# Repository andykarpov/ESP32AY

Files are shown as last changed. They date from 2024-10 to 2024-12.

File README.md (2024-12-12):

# ESP32AY multiformat Turbo Sound player 

## (archived outdated fork, please use the original repo for fresh sources including the PCB)

ESP32 based AY Turbo Sound multiformat player

## Fast flash firmware avaliable on [Alex Spawn OTA web page](https://ota.alexspawn.ru)

## Features
### Supported formats:
- .ayl - [Ay_Emul](https://bulba.untergrund.net/emulator_e.htm) by Sergey Bulba own playlist format
- .pt1 - Pro Tracker v1 file format
- .pt2 - Pro Tracker v2 file format
- .pt3 - Pro Tracker v3 (include Turbo Sound on two AY chips) file format
- .stc - Sound Tracker file format
- .stp - Sound Tracker Pro file format
- .asc - Sound Master file format 
- .psc - Pro Sound Creator file format
- .sqt - SQ Tracker file format
- .ay  - AY file format
- .psg - Programmable Sound Generator file format
- .rsf - Registers Stream Flow file format
- .yrg - [Custom AVR-AY format](https://www.avray.ru/ru/avr-ay-player/)
- UART mode (available in player settings menu as Player source)

### Controls
- Encoder Hold - change mode player/file browser
- Encoder Click - in player mode - play/pause; in file browser mode select track/playlist/directory; select - in config mode
- Encoder Double click - in player mode - open settings
- Encoder Push and turn right - fast forward (for ay format change next subsong)
- Encoder Push and turn left - slow down (for ay format change previous subsong)
- Left button click/hold - volume - (in player mode); cancel - in config mode
- Right button click/hold - volume + (in player mode)
- Left button double click - change AY clock (in player mode)
- Right button double click - change play mode: all/shuffle/once (in player mode)

### Playing modes:
- Playing all tracks (in folder/playlist)
- Playing random track (in folder/playlist)
- Playing once track (loop)

### Supports fully realtime file browser

### Supports realtime AY layers change:
- ABC
- ACB
- BAC
- BCA
- CAB
- CBA

### Supports realtime AY clock change:
- ZX SPECTRUM - 1773400 Hz
- PENTAGON - 1750000 Hz
- MSX - 1789772 Hz
- CPC - 1000000 Hz
- ATARI ST - 2000000 Hz

### Built-in battery

### Built-in charger and indication on LED and TFT

### Built-in headphones stereo amplifier controlled by I2C bus

## Demo video with digital sound record:

Watch the video (https://youtu.be/-dr-m1xszBs)

### UPD 22.10.2024
- Add new feature: "UART mode" with AVR-AY player through UART.

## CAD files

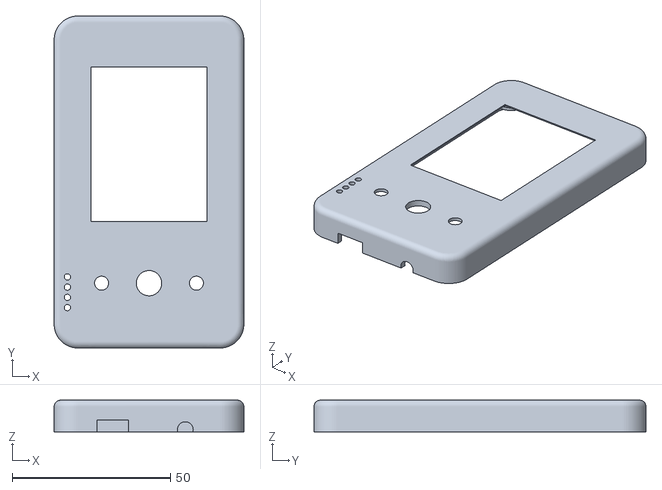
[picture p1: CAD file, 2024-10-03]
Case/ESP32AYTopTypeC.stl
60.0 x 105.0 x 10.00

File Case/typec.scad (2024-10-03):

$fn = 100;

pcb = "ESP32AY.stl";

if (false)
{
  translate([0, 0, 0.6]) 
  {
    rotate([0,0,0]) color("lightgray") import(pcb);
  }
}


difference() {
    
    #import("ESP32AYTop.stl");

    translate([36, -115, -1.45])
        rotate([0, 90, 90])
            cube([4, 10, 30], true);
}

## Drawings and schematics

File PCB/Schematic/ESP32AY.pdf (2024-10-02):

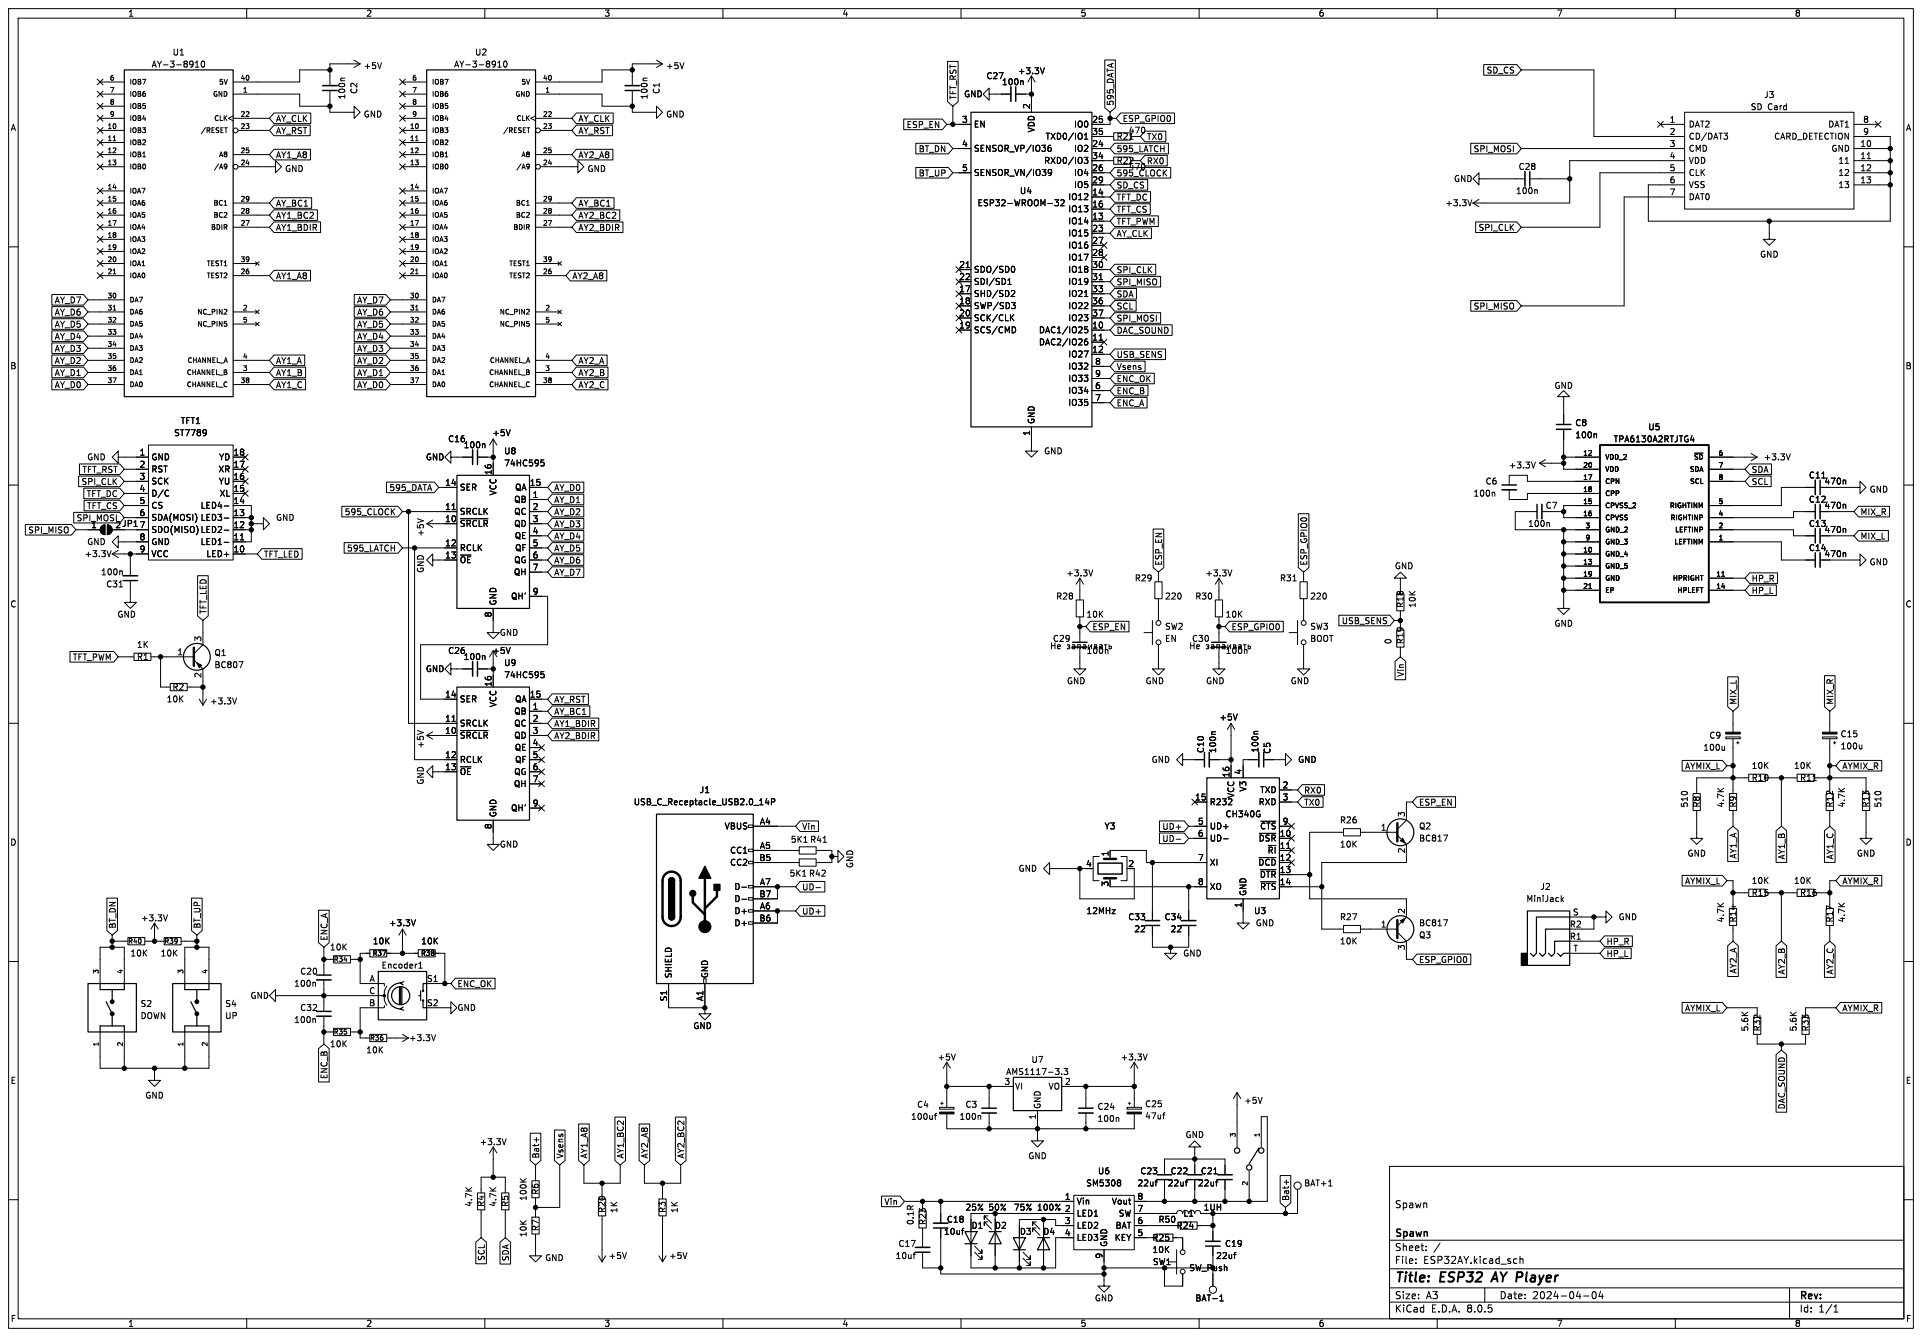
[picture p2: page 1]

2 SCK/CLK 20 SDO/SD0 21 SDI/SD1 22

LED4- 14 XL 15 YU 16 XR 17 YD 18 RST 2 SCK 3 D/C 4 CS 5 SDA(MOSI) 6 SDO(MISO) 7 GND 8 VCC 9

4 UD+ 5 UD- 6 XI 7 XO 8 ~{CTS}9 C23

1 ~{DSR} 10 ~{RI} 11 ~{DCD} 12 ~{DTR} 13 ~{RTS} 14 R232 15 VCC 16 TXD 2 RXD 3 V3
U3 CH340GGND

4 UD+ 5 UD- 6 XI 7 XO 8 ~{CTS}9 U3 CH340G

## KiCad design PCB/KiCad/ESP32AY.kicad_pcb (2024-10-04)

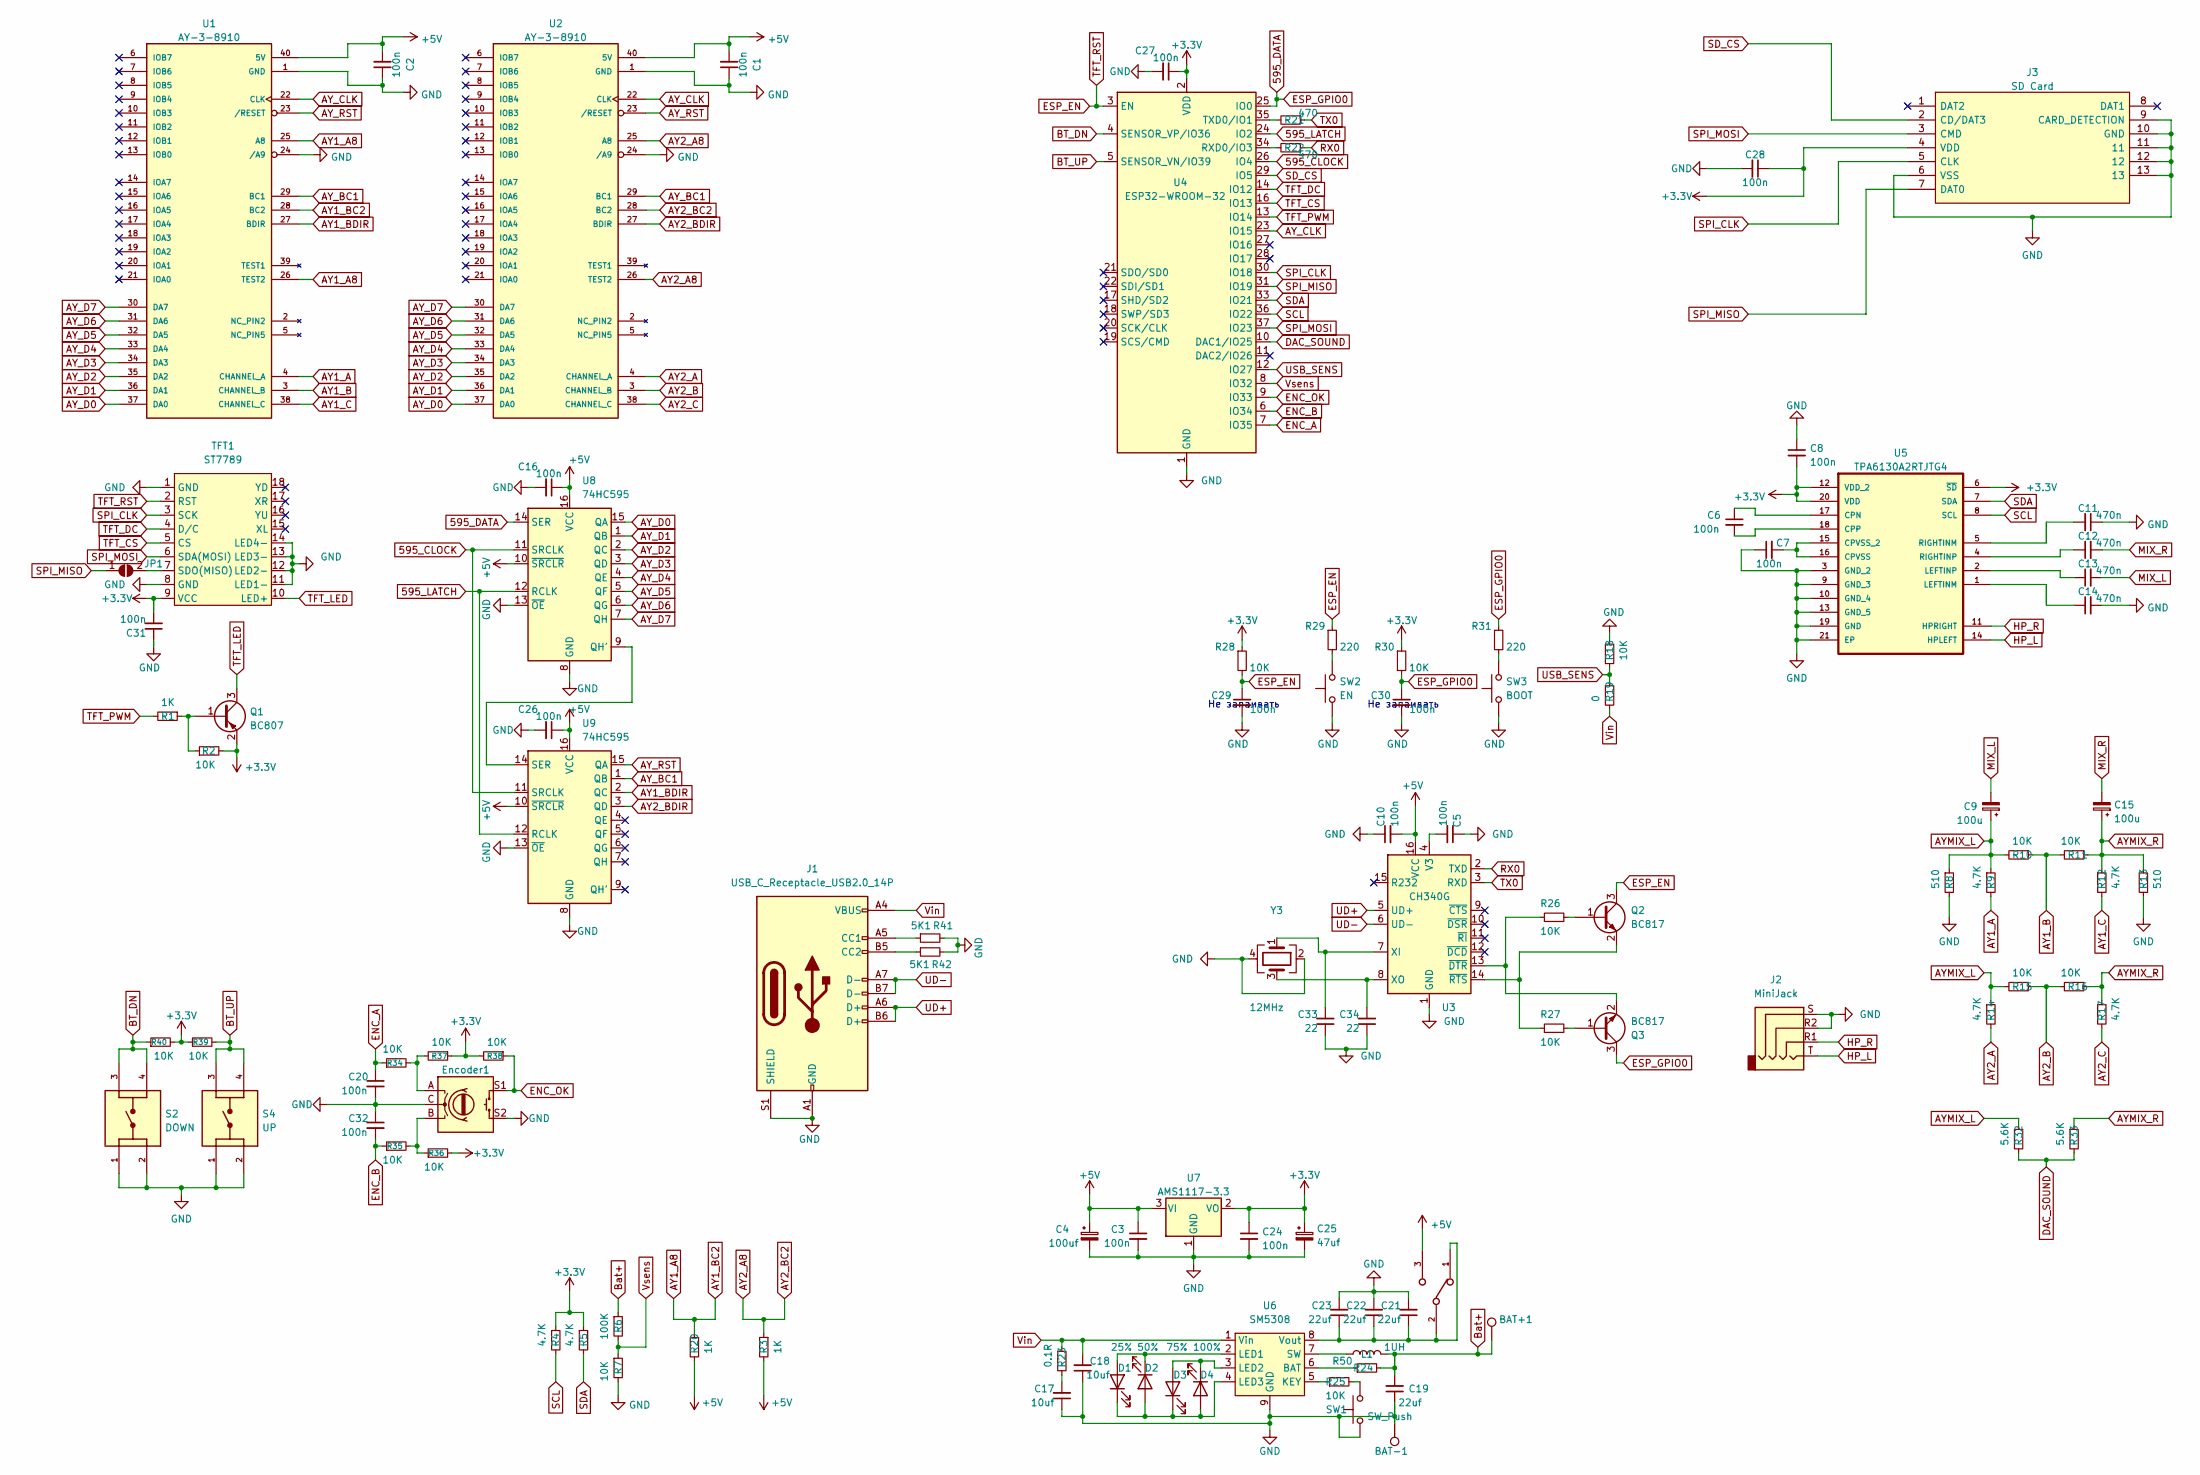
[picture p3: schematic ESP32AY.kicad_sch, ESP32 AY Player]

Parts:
BAT+1: BAT+; TestPoint_Pad_D3.0mm
BAT-1: BAT-; TestPoint_Pad_D3.0mm
C1, C2, C3, C5, C6, C7, C8, C10, C16, C20, C24, C26, C27, C28, C29, C30, C31, C32: 100n; C_0805_2012Metric_Pad1.18x1.45mm_HandSolder
C4: 100uf; CP_EIA-7343-31_Kemet-D-uni
C9, C15: 100u; CP_EIA-7343-31_Kemet-D_Pad2.25x2.55mm_HandSolder
C11, C12, C13, C14: 470n; C_0805_2012Metric_Pad1.18x1.45mm_HandSolder
C17, C18: 10uf; C_0805_2012Metric_Pad1.18x1.45mm_HandSolder
C19, C21, C22: 22uf; C_0805_2012Metric_Pad1.18x1.45mm_HandSolder
C23: 22uf; C_0805_2012Metric
C25: 47uf; CP_EIA-7343-31_Kemet-D-uni
C33, C34: 22; C_0805_2012Metric_Pad1.18x1.45mm_HandSolder
D1: 25%; LED_0805_2012Metric
D2: 50%; LED_0805_2012Metric
D3: 75%; LED_0805_2012Metric
D4: 100%; LED_0805_2012Metric
Encoder1: RotaryEncoder_Switch; RotaryEncoder_Alps_EC11E-Switch_Vertical_H20mm
J1: USB_C_Receptacle_USB2.0_14P; USB_C_Receptacle_G-Switch_GT-USB-7010ASV
J2: MiniJack; AUDIO_JACK_3.5MM_SMD_TRRS_rounded_mixed
J3: SD Card; TFP09212B; Manufacturer_Part_Number TFP09-2-12B
JP1: jumper; SolderJumper-2_P1.3mm_Bridged_RoundedPad1.0x1.5mm
L1: 1UH; L_7.3x7.3_H3.5
Q1: BC807; SOT-23
Q2, Q3: BC817; SOT-23
R1, R3, R20: 1K; R_0805_2012Metric_Pad1.20x1.40mm_HandSolder
R2, R7, R10, R11, R15, R16, R18, R26, R27, R28, R30, R34, R35, R36, R37, R38, R39, R40: 10K; R_0805_2012Metric_Pad1.20x1.40mm_HandSolder
R4, R5, R9, R12, R14, R17: 4.7K; R_0805_2012Metric_Pad1.20x1.40mm_HandSolder
R6: 100K; R_0805_2012Metric_Pad1.20x1.40mm_HandSolder
R8, R13: 510; R_0805_2012Metric_Pad1.20x1.40mm_HandSolder
R19: 0; R_0805_2012Metric_Pad1.20x1.40mm_HandSolder
R21, R22: 470; R_0805_2012Metric_Pad1.20x1.40mm_HandSolder
R23: 0.1R; R_0805_2012Metric
R24: R50; R_0805_2012Metric
R25: 10K; R_0805_2012Metric
R29, R31: 220; R_0805_2012Metric_Pad1.20x1.40mm_HandSolder
R32, R33: 5.6K; R_0805_2012Metric_Pad1.20x1.40mm_HandSolder
R41, R42: 5K1; R_0805_2012Metric_Pad1.20x1.40mm_HandSolder
S2: DOWN; SW_Push_1P1T_NO_6x6mm_H9.5mm
S4: UP; SW_Push_1P1T_NO_6x6mm_H9.5mm
S6: EG1213; SW_EG1213
SW1: SW_Push; SolderJumper-2_P1.3mm_Open_RoundedPad1.0x1.5mm
SW2: EN; SW_SPST_PTS810_handsoldering
SW3: BOOT; SW_SPST_PTS810_handsoldering
TFT1: ST7789
U1, U2: AY-3-8910; DIP-40_W15.24mm_Socket
U3: CH340G; SOIC-16_3.9x9.9mm_P1.27mm
U4: ESP32-WROOM-32
U5: TPA6130A2RTJTG4; QFN50P400X400X80-21N; MPN TPA6130A2RTJTG4
U6: SM5308; HSOP-8-1EP_3.9x4.9mm_P1.27mm_EP2.41x3.1mm
U7: AMS1117-3.3; SOT-223-3_TabPin2
U8, U9: 74HC595; SO-16_5.3x10.2mm_P1.27mm
Y3: 12MHz; Crystal_SMD_3225-4Pin_3.2x2.5mm_HandSoldering; PARTREV 10/24/2022

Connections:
595_CLOCK: U4.26 (IO4), U8.11 (SRCLK), U9.11 (SRCLK)
595_DATA: C30.1, Q3.3 (C), R30.2, R31.1, U4.25 (IO0), U8.14 (SER)
595_LATCH: U4.24 (IO2), U8.12 (RCLK), U9.12 (RCLK)
+3.3V: C8.2, C24.1, C25.1, C27.1, C28.1, C31.2, J3.4 (VDD), Q1.2 (E), R2.2, R4.1, R5.1, R28.1, R30.1, R36.2, R37.1, R38.2, R39.1, R40.2, TFT1.9 (VCC), U4.2 (VDD), U5.6 (~SD), U5.12 (VDD_2), U5.20 (VDD), U7.2 (VO)
+5V: C1.2, C2.2, C3.1, C4.1, C10.2, C16.1, C26.1, R3.2, R20.2, S6.3, U1.40 (5V), U2.40 (5V), U3.16 (VCC), U7.3 (VI), U8.10 (~SRCLR), U8.16 (VCC), U9.10 (~SRCLR), U9.16 (VCC)
AY1_A: R9.2, U1.4 (CHANNEL_A)
AY1_A8: R20.1, U1.25 (A8), U1.26 (TEST2), U1.28 (BC2)
AY1_B: R10.1, R11.2, U1.3 (CHANNEL_B)
AY1_BDIR: U1.27 (BDIR), U9.2 (QC)
AY1_C: R12.2, U1.38 (CHANNEL_C)
AY2_A: R14.2, U2.4 (CHANNEL_A)
AY2_A8: R3.1, U2.25 (A8), U2.26 (TEST2), U2.28 (BC2)
AY2_B: R15.1, R16.2, U2.3 (CHANNEL_B)
AY2_BDIR: U2.27 (BDIR), U9.3 (QD)
AY2_C: R17.2, U2.38 (CHANNEL_C)
AYMIX_L: C9.1, R8.1, R9.1, R10.2, R14.1, R15.2, R32.1
AYMIX_R: C15.1, R11.1, R12.1, R13.1, R16.1, R17.1, R33.1
AY_BC1: U1.29 (BC1), U2.29 (BC1), U9.1 (QB)
AY_CLK: U1.22 (CLK), U2.22 (CLK), U4.23 (IO15)
AY_D0: U1.37 (DA0), U2.37 (DA0), U8.15 (QA)
AY_D1: U1.36 (DA1), U2.36 (DA1), U8.1 (QB)
AY_D2: U1.35 (DA2), U2.35 (DA2), U8.2 (QC)
AY_D3: U1.34 (DA3), U2.34 (DA3), U8.3 (QD)
AY_D4: U1.33 (DA4), U2.33 (DA4), U8.4 (QE)
AY_D5: U1.32 (DA5), U2.32 (DA5), U8.5 (QF)
AY_D6: U1.31 (DA6), U2.31 (DA6), U8.6 (QG)
AY_D7: U1.30 (DA7), U2.30 (DA7), U8.7 (QH)
AY_RST: U1.23 (/RESET), U2.23 (/RESET), U9.15 (QA)
BT_DN: R40.1, S2.3, S2.4, U4.4 (SENSOR_VP/IO36)
BT_UP: R39.2, S4.3, S4.4, U4.5 (SENSOR_VN/IO39)
Bat+: BAT+1.1, C19.2, L1.2, R6.1, R24.2
DAC_SOUND: R32.2, R33.2, U4.10 (DAC1/IO25)
ENC_A: C20.1, R34.1, U4.7 (IO35)
ENC_B: C32.2, R35.1, U4.6 (IO34)
ENC_OK: Encoder1.S1, R38.1, U4.9 (IO33)
ESP_EN: C29.1, Q2.3 (C), R28.2, R29.1, TFT1.2 (RST), U4.3 (EN)
GND: BAT-1.1, C1.1, C2.1, C3.2, C4.2, C5.1, C7.1, C8.1, C10.1, C11.1, C14.2, C16.2, C17.1, C18.1, C19.1, C20.2, C21.2, C22.2, C23.2, C24.2, C25.2, C26.2, C27.2, C28.2, C29.2, C30.2, C31.1, C32.1, C33.1, C34.1, Encoder1.C, Encoder1.S2, J1.A1 (GND), J1.A12 (GND), J1.B1 (GND), J1.B12 (GND), J1.S1 (SHIELD), J2.R2, J2.S, J3.6 (VSS), J3.9 (CARD_DETECTION), J3.10 (GND), J3.11, J3.12, J3.13, R7.2, R8.2, R13.2, R18.1, R41.2, R42.2, S2.1, S2.2, S4.1, S4.2, SW1.1, SW2.1 (A), SW3.1 (A), TFT1.1 (GND), TFT1.8 (GND), TFT1.11 (LED1-), TFT1.12 (LED2-), TFT1.13 (LED3-), TFT1.14 (LED4-), U1.1 (GND), U1.24 (/A9), U2.1 (GND), U2.24 (/A9), U3.1 (GND), U4.1 (GND), U4.15 (GND), U4.38 (GND), U4.39 (GND), U5.3 (GND_2), U5.9 (GND_3), U5.10 (GND_4), U5.13 (GND_5), U5.19 (GND), U5.21 (EP), U6.9 (GND), U7.1 (GND), U8.8 (GND), U8.13 (~OE), U9.8 (GND), U9.13 (~OE), Y3.2, Y3.4
HP_L: J2.T, U5.14 (HPLEFT)
HP_R: J2.R1, U5.11 (HPRIGHT)
MIX_L: C9.2, C13.2
MIX_R: C12.2, C15.2
unnamed: C17.2, R23.2
unnamed: D1.2 (A), D2.1 (K), U6.2 (LED1)
unnamed: D1.1 (K), D2.2 (A), D3.1 (K), D4.2 (A), U6.4 (LED3)
unnamed: D3.2 (A), D4.1 (K), U6.3 (LED2)
unnamed: Encoder1.A, R34.2, R37.2
unnamed: Encoder1.B, R35.2, R36.1
unnamed: J1.A5 (CC1), R41.1
unnamed: J1.B5 (CC2), R42.1
unnamed: JP1.2 (B), TFT1.7 (SDO(MISO))
unnamed: Q1.1 (B), R1.1, R2.1
unnamed: Q2.1 (B), R26.2
unnamed: Q2.2 (E), R27.1, U3.14 (~RTS)
unnamed: Q3.1 (B), R27.2
unnamed: Q3.2 (E), R26.1, U3.13 (~DTR)
unnamed: R25.2, SW1.2
unnamed: R29.2, SW2.2 (B)
unnamed: R31.2, SW3.2 (B)
unnamed: C5.2, U3.4 (V3)
unnamed: C33.2, U3.7 (XI), Y3.1
unnamed: C34.2, U3.8 (XO), Y3.3
unnamed: R22.2, U4.34 (RXD0/IO3)
unnamed: R21.2, U4.35 (TXD0/IO1)
unnamed: C6.1, U5.17 (CPN)
unnamed: C6.2, U5.18 (CPP)
unnamed: C7.2, U5.15 (CPVSS_2), U5.16 (CPVSS)
unnamed: C14.1, U5.1 (LEFTINM)
unnamed: C13.1, U5.2 (LEFTINP)
unnamed: C11.2, U5.5 (RIGHTINM)
unnamed: C12.1, U5.4 (RIGHTINP)
unnamed: R24.1, U6.6 (BAT)
unnamed: R25.1, U6.5 (KEY)
unnamed: L1.1, U6.7 (SW)
unnamed: C21.1, C22.1, C23.1, S6.1, S6.2, U6.8 (Vout)
unnamed: U8.9 (QH'), U9.14 (SER)
RX0: R22.1, U3.2 (TXD)
SCL: R4.2, U4.36 (IO22), U5.8 (SCL)
SDA: R5.2, U4.33 (IO21), U5.7 (SDA)
SD_CS: J3.2 (CD/DAT3), U4.29 (IO5)
SPI_CLK: J3.5 (CLK), TFT1.3 (SCK), U4.30 (IO18)
SPI_MISO: J3.7 (DAT0), JP1.1 (A), U4.31 (IO19)
SPI_MOSI: J3.3 (CMD), TFT1.6 (SDA(MOSI)), U4.37 (IO23)
TFT_CS: TFT1.5 (CS), U4.16 (IO13)
TFT_DC: TFT1.4 (D/C), U4.14 (IO12)
TFT_LED: Q1.3 (C), TFT1.10 (LED+)
TFT_PWM: R1.2, U4.13 (IO14)
TX0: R21.1, U3.3 (RXD)
UD+: J1.A6 (D+), J1.B6 (D+), U3.5 (UD+)
UD-: J1.A7 (D-), J1.B7 (D-), U3.6 (UD-)
USB_SENS: R18.2, R19.1, U4.12 (IO27)
Vin: C18.2, J1.A4 (VBUS), J1.A9 (VBUS), J1.B4 (VBUS), J1.B9 (VBUS), R19.2, R23.1, U6.1 (Vin)
Vsens: R6.2, R7.1, U4.8 (IO32)

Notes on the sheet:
Не запаивать

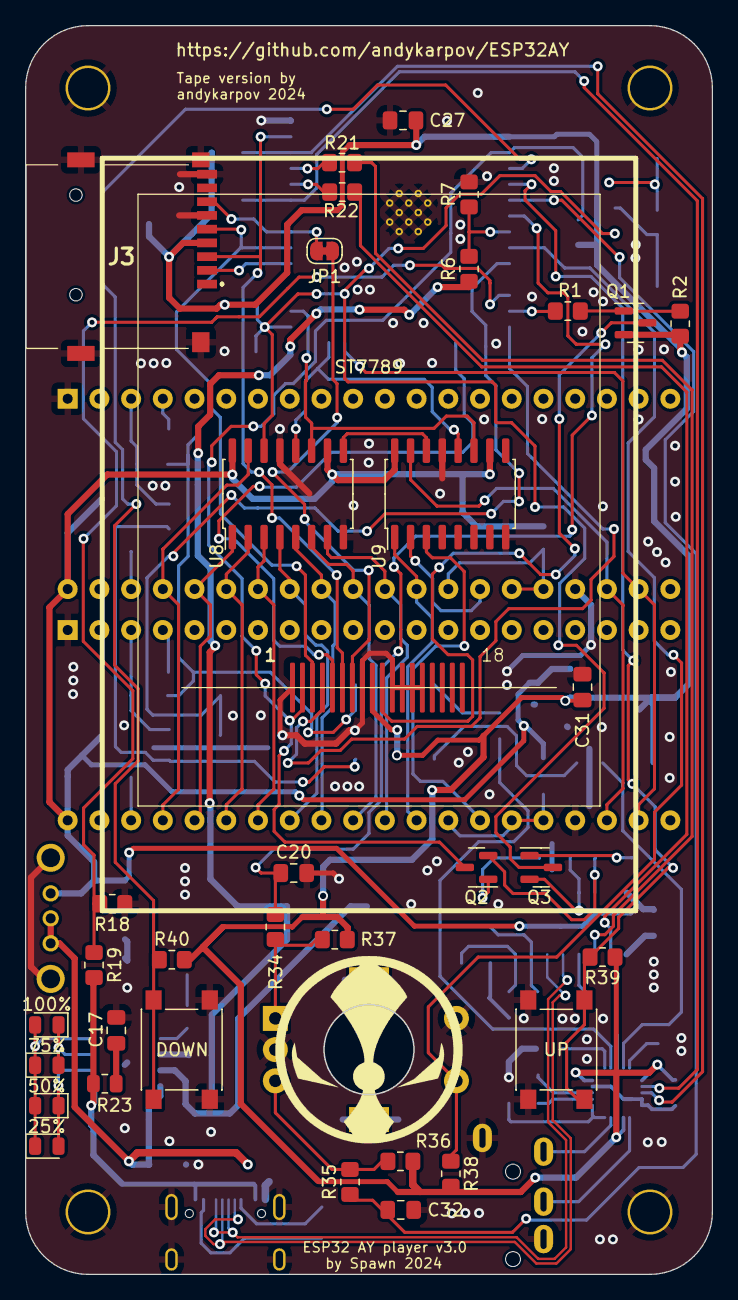
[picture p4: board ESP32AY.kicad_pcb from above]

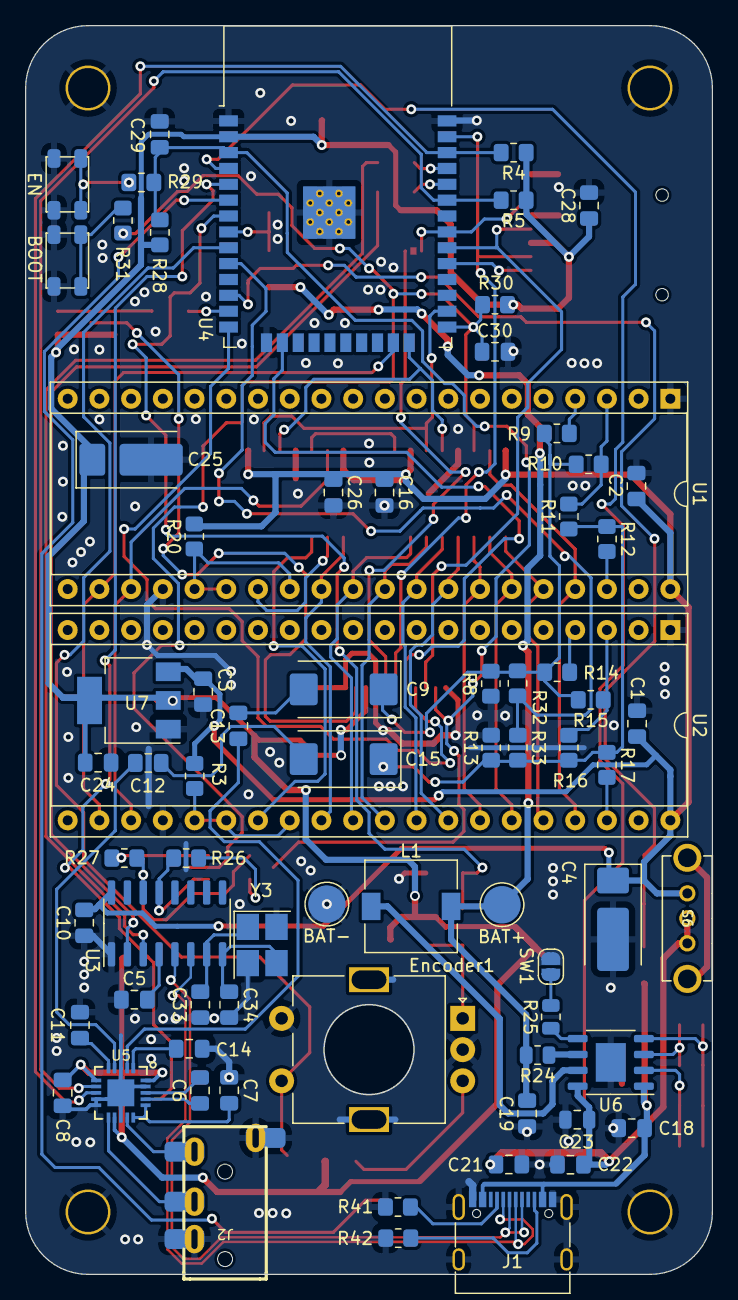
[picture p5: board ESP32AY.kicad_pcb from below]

Board: 2 copper layers, 55.0 x 100.0 mm, 108 parts (72 on the bottom side), 92 nets.

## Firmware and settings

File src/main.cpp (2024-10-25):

#include <Arduino.h>
#include <SPI.h>
#include <SdFat.h>
#include "esp_task_wdt.h"

#include "defines.h"

#include "res/select.h"
#include "res/move.h"
#include "res/cancel.h"

#include "amp.h"
#include "keypad.h"
#include "tftui.h"
#include "config.h"
#include "playlist.h"
#include "browser.h"

#include "sound.h"
#include "eq.h"
#include "ay.h"
#include "ayflyw.h"

#include "players/ASCPlay.h"
#include "players/PSCPlay.h"
#include "players/PT1Play.h"
#include "players/PT2Play.h"
#include "players/PT3Play.h"
#include "players/SQTPlay.h"
#include "players/STCPlay.h"
#include "players/STPPlay.h"
#include "players/AYPlay.h"
#include "players/PSGPlay.h"

#include "player.h"
#include "uart.h"

void setup(){
  display_brightness(0);
  config_load();
  initVoltage();
  TFTInit();
  buttonsSetup();
  DACInit();
  AYInit();
  ampInit();
  introTFT();
  delay(2000);
  show_frame();
  playerSourceChange(); // ayplaycore or uartplaycore
  checkSDonStart();
  muteAYBeep();
}

void loop(){
  generalTick();
  player();
  switch(PlayerCTRL.screen_mode){
    case SCR_PLAYER:
      player_screen();
      break;
    case SCR_BROWSER:
      browser_screen(Config.isBrowserPlaylist);
      break;
    case SCR_CONFIG:
      config_screen();
      break;
    case SCR_RESET_CONFIG:
      config_reset_default_screen();
      break;
    case SCR_ABOUT:
      config_about_screen();
      break;
    case SCR_SDEJECT:
      sdEject();
      checkSDonStart();
      break;
  }
  scrTimeout();
  esp_task_wdt_reset();
}

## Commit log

2024-10-02 Replaced miniUSB with typeC, changed small buttons, changed 12MHz crystal footprint
    [ESP32AY.kicad_pcb, ESP32AY.kicad_sch, bom.csv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]
2024-10-03 Replaced 1206 to 0805 hand soldering footprints
    [ESP32AY.kicad_pcb, ESP32AY.kicad_sch]
2024-10-03 OpenSCAD project and top case with bigger hole for type-c
    [ESP32AYTopTypeC.stl, typec.scad]
2024-10-03 Changed tantalum cap footprints
    [ESP32AY.kicad_pcb, ESP32AY.kicad_sch]
2024-10-04 Small silskreen fixes, moved tiny buttons on the one side
    [ESP32AY.kicad_pcb]
2024-10-25 upstream sync (#3)
    * udate encButton library
    * upate version build
    * add: new feature - Playing over UART
    * update: firmware with v3.2
    * update readme
    * fix: settings menu bug
    ---------
    [main.cpp]
